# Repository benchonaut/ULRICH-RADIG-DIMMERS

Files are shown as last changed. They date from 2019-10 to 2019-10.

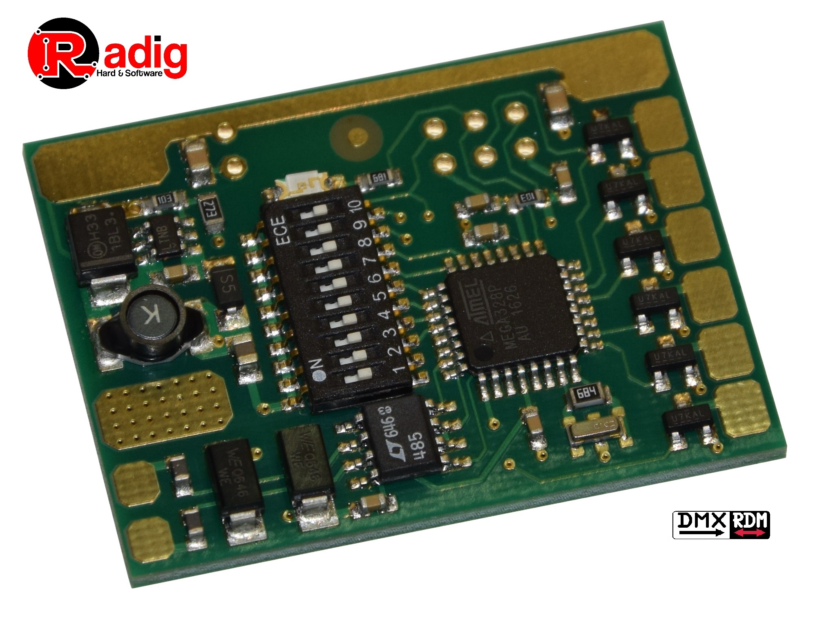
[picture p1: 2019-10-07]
DMX_6channel_LED_RDM/mini_DMX_RDM_Controller.JPG

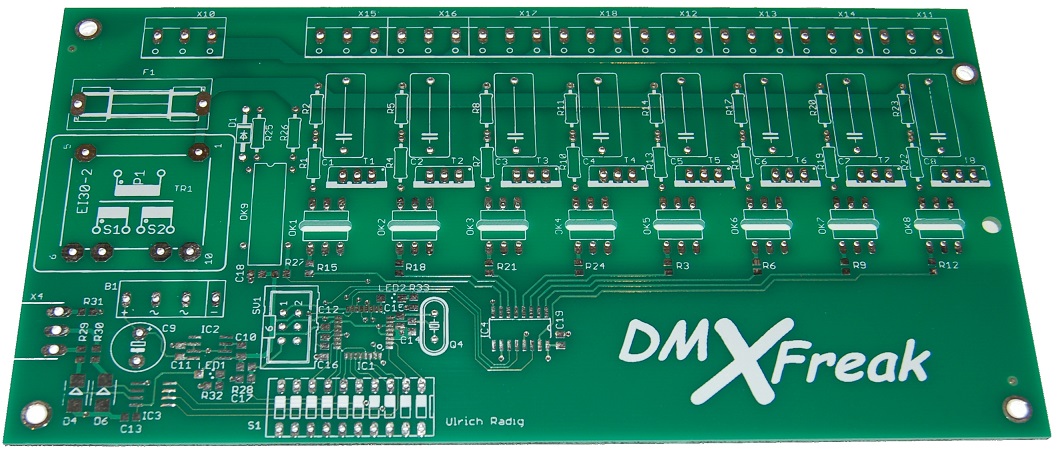
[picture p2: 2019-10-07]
DMX-8channel-V3/Bilder/DSC_0211.JPG

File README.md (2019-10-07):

## fixed code for dimmers from  ulrich-radig.de

#### intro:
in the 3 and 8 channel projects there are fixed 
dimmercurves from the forum named ...SKALIERT.c , 

( with the original calculation , dimming starts from ~35 % or dmx value 75 , this is also the point where voltage drops below 10v)

Since 
> (255-DMX_VAL)/2

will be max 128 or 127  and the dimmmer has 90 possible values from phase cutting ,
 the transformation is done as suggested in his forum[1] via valMap

hint: the values are reversed 100%=0 ,0%=90 internal 

#### install:
-> atmel studio 7 -> new project -> c++ -> stk5000 (find com .. ) -> atmega328p -> insert sourceode -> build solution (f7) -> "tools→add target" -> "tools→device programming" -> "read"(top) ->memories (check for build to appear) -> erase flash -> program 

[1]  https://www.ulrichradig.de/forum/viewtopic.php?f=53&t=2656s

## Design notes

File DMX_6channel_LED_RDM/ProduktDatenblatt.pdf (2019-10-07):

## 6 Kanal DMX RDM LED Controller

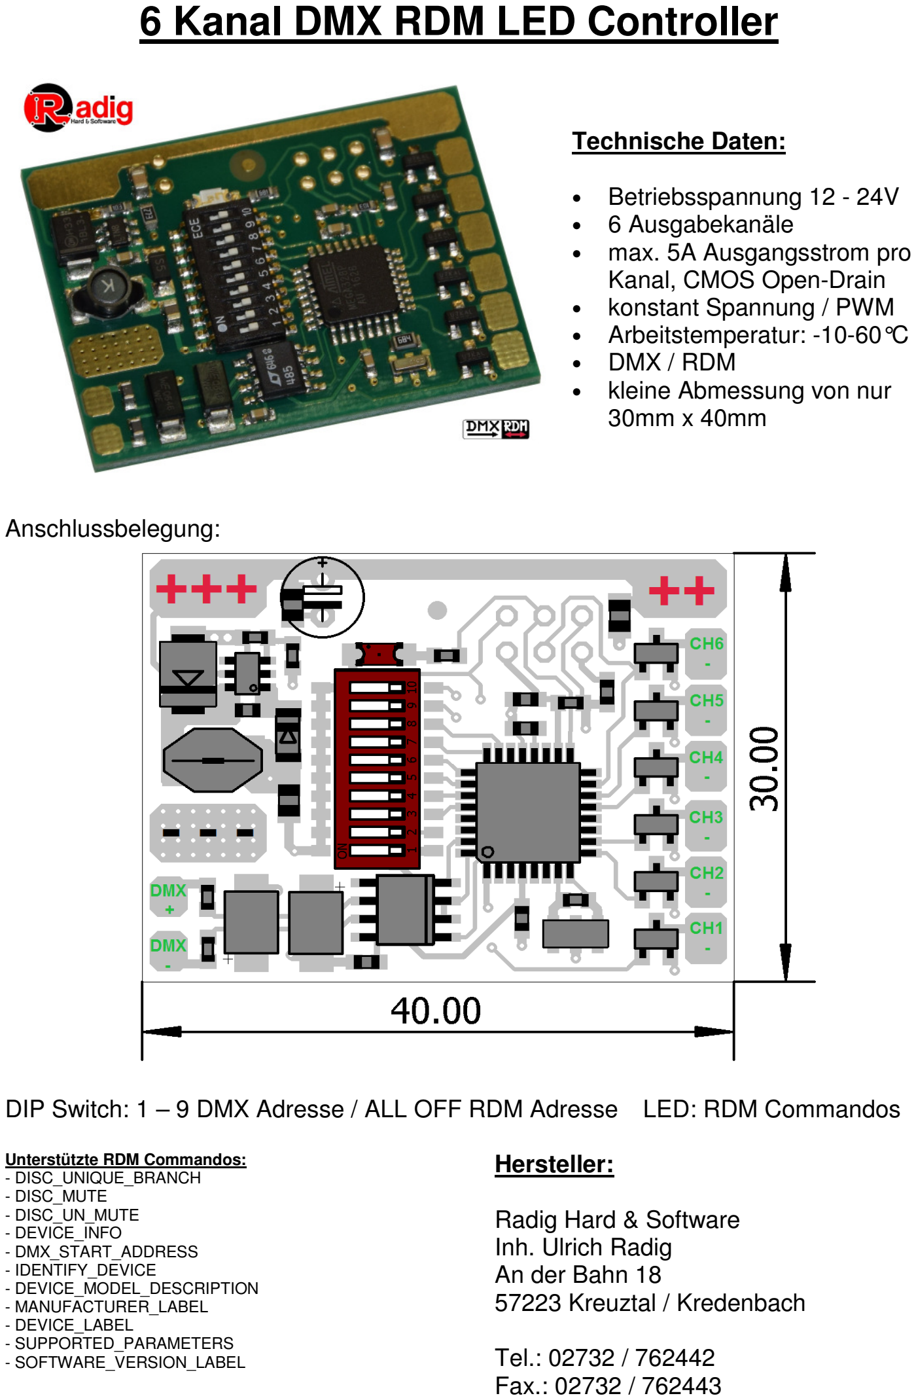
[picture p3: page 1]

Technische Daten:

- Betriebsspannung 12 - 24V
- 6 Ausgabekanäle
- max. 5A Ausgangsstrom pro Kanal, CMOS Open-Drain
- konstant Spannung / PWM
- Arbeitstemperatur: -10-60°C
- DMX / RDM
- kleine Abmessung von nur 30mm x 40mm

Anschlussbelegung:

DIP Switch: 1 – 9 DMX Adresse / ALL OFF RDM Adresse LED: RDM Commandos

Unterstützte RDM Commandos:
- DISC_UNIQUE_BRANCH
- DISC_MUTE
- DISC_UN_MUTE
- DEVICE_INFO
- DMX_START_ADDRESS
- IDENTIFY_DEVICE
- DEVICE_MODEL_DESCRIPTION
- MANUFACTURER_LABEL
- DEVICE_LABEL
- SUPPORTED_PARAMETERS
- SOFTWARE_VERSION_LABEL

Hersteller:

Radig Hard & Software
Inh. Ulrich Radig
An der Bahn 18
57223 Kreuztal / Kredenbach

Tel.: 02732 / 762442
Fax.: 02732 / 762443

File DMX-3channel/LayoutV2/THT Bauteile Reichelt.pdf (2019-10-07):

reichelt elektronik GmbH & Co. KG Elektronikring 1
26452 Sande

Tel.: +49 (0)4422 955-333
Fax.: +49 (0)4422 955-111
www.reichelt.de
Datum: 26.Aug.2012

Warenkorb

Artikel-Nr. | Bezeichnung | WG | Menge | Einzelpreis incl. MwSt.

Gesamtpreis
incl. MwSt.
B40C1500-WW+ | Brückengleichrichter | 1 | 1 | 0,26 € | 0,26 €
RAD 220/25 | Elektrolytkondensator, 8x11,5mm, RM 3,5mm | 1 | 1 | 0,040 € | 0,04 €
1N 4007 | Gleichrichterdiode, DO41, 1000V, 1A | 1 | 1 | 0,020 € | 0,02 €
PL 112000 | Sicherungshalter, 5x20mm, max. 6,3A-250V | 1 | 4 | 0,13 € | 0,50 €
TRÄGE 0,05A | Feinsicherung 5x20mm, träge 0,05A | 1 | 1 | 0,82 € | 0,82 €
TRÄGE 1,6A | Feinsicherung 5x20mm, träge 1,6A | 1 | 3 | 0,32 € | 0,96 €
S202 S01 | Solid-State-Relais, U: 600V, IT: 8,0A, Ift: 8mA | 1 | 3 | 3,65 € | 10,95 €
CAF 3,5-2,7 | Stromkompensierte Drossel, 2,7mH, 15/25mm | 1 | 1 | 1,95 € | 1,95 €
CNY 65 | OPTOKOPPLER | 1 | 1 | 1,00 € | 1,00 €
WSL 6G | Wannenstecker, 6-polig, gerade | 1 | 1 | 0,16 € | 0,16 €
1/4W 33K | Kohleschichtwiderstand 1/4W, 5%, 33 K-Ohm | 1 | 2 | 0,10 € | 0,21 €
DP 10 | Piano-Dip-Schalter, 10-polig | 1 | 1 | 0,64 € | 0,64 €
EI 30/12,5 209 | Trafo 1,5VA, 2x 9V, 2x 83mA | 1 | 1 | 2,50 € | 2,50 €
AKL 330-03 | Wannenstecker für AKL 349, 3-pol, RM5,0 | 1 | 4 | 0,40 € | 1,60 €
AKL 349-03 | Anschlussklemmensystem 3-pol, RM5,0 | 1 | 4 | 0,82 € | 3,28 €
PSS 254/3G | Printstecker, Einzelstecker, gerade, 3-polig | 1 | 1 | 0,050 € | 0,05 €
PSK 254/3W | Kupplungs-Leergehäuse, Crimptechnik, 3-polig | 1 | 1 | 0,050 € | 0,05 €
PSK-KONTAKTE | Crimpkontakte für psk 254/..., 20 Stück | 1 | 1 | 0,23 € | 0,23 €
Warenwert | | | | | 25,22 €
| | | | | ============
Zuzüglich Versandkosten innerhalb Deutschlands für ca. 0,2 kg bei Zahlung per Nachnahme | 8,06 €
Zuzüglich Versandkosten innerhalb Deutschlands für ca. 0,2 kg bei Zahlung per Bankeinzug/Re/Vorkasse | 5,60 €

Alle Preise in Euro inklusive gesetzl. Mehrwertsteuer.

Mit freundlichen Grüßen
Ihr reichelt elektronik Team
Notebook, PC Zubehör, Festplatte und Elektronik bei Reichelt | Seite 1 von 1
http://www.reichelt.de/index.html?IW=1;ACTION=505;SID=10UDpS3H8AAAIAA... | 26.08.2012

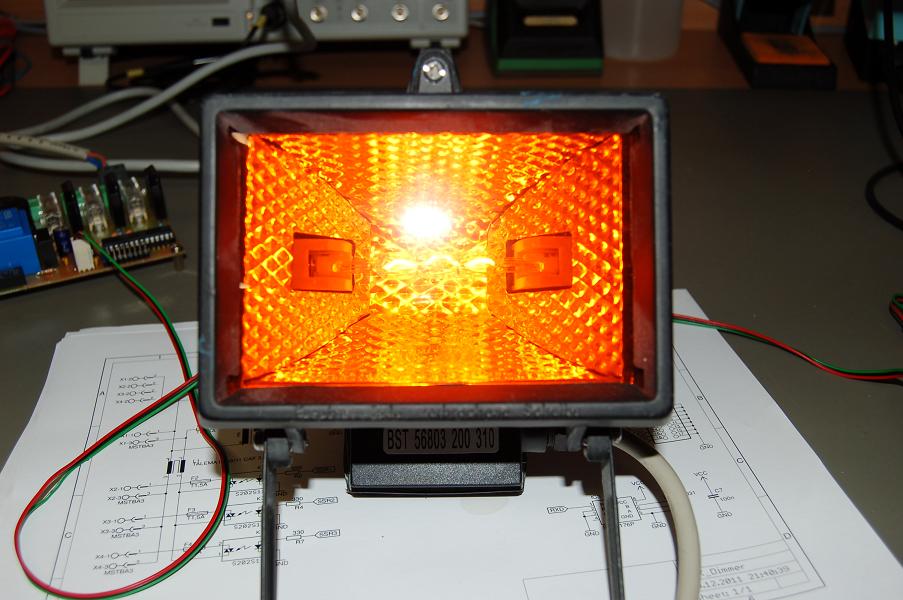
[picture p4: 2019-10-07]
DMX-3channel/Bilder/Strahler_Baumarkt.JPG

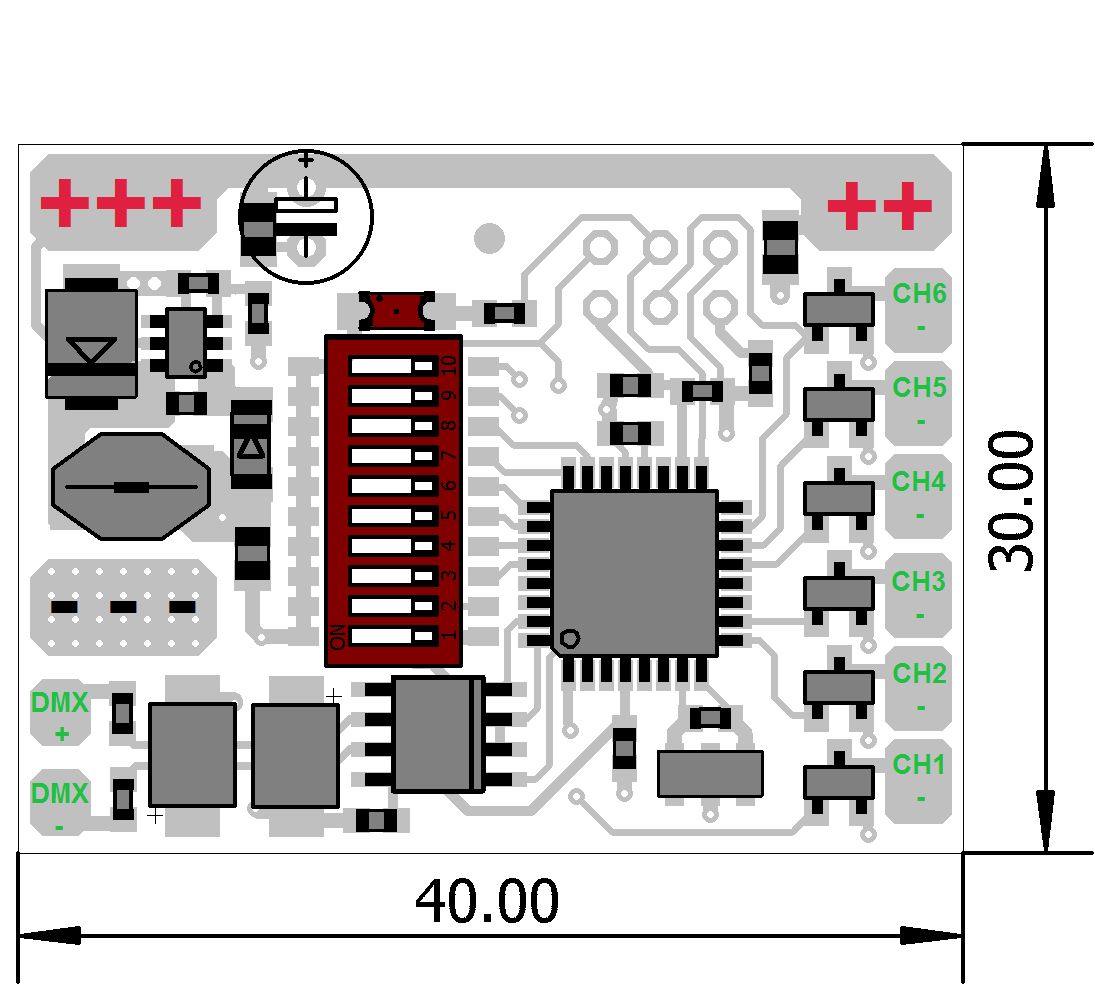
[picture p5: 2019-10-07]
DMX_6channel_LED_RDM/TOP.bmp

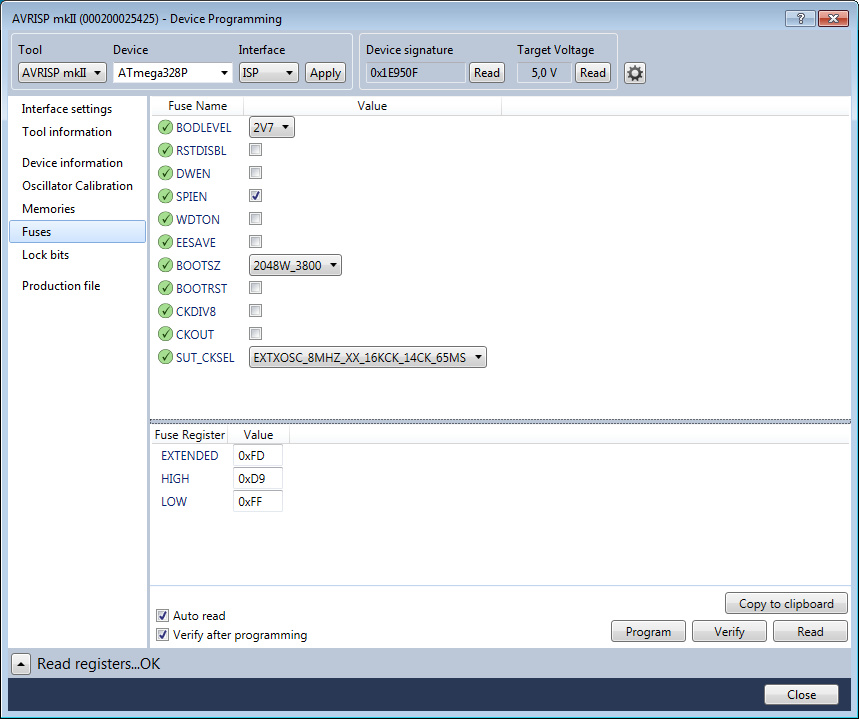
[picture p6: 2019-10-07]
DMX-8channel-V3/Hexfile/FuseBits.bmp

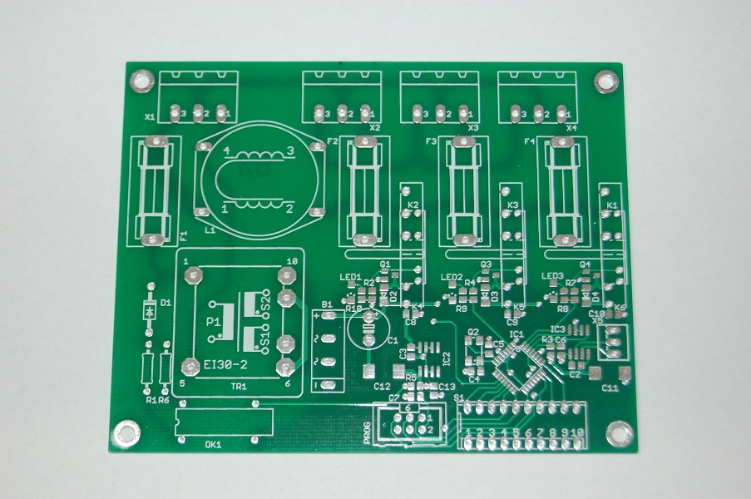
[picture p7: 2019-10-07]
DMX-3channel/Bilder/DMX Dimmer.JPG

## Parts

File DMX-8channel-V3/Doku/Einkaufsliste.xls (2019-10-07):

Part | Value | Menge | Stück Preis | Gesamt Preis | Lieferant | Bestellnr.
B1 | B40C2300/1500 +AC- | 1 | 0.33 € | 0.33 € | Reichelt | B40C1500-WW+ (https://www.reichelt.de/Gleichrichter/B40C1500-WW-/3/index.html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)
C1..C8 | 0.22µF 275V~ | 8 | 0.25 € | 2.00 € | Reichelt | PAN-X2-220N (https://www.reichelt.de/Funkentstoerkondensatoren/PAN-X2-220N/3/index.html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)
C9 | 220µF 35V | 1 | 0.05 € | 0.05 € | Reichelt | RAD 220/35 (https://www.reichelt.de/Elkos-radial-85-C/RAD-220-35/3/index.html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)
C10..C13,C16..C19 | 100n BF0805 | 8 | 0.04 € | 0.32 € | Reichelt | X7R-G0805 100N (https://www.reichelt.de/Vielschicht-SMD-G0805/X7R-G0805-100N/3/index.html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)
C14,C15 | 22p BF0805 | 2 | 0.04 € | 0.08 € | Reichelt | NPO-G0805 22P (https://www.reichelt.de/Vielschicht-SMD-G0805/NPO-G0805-22P/3/index.html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)
D1 | 1N4007 | 1 | 0.04 € | 0.04 € | Reichelt | 1N 4007 (https://www.reichelt.de/1N-UF-AA-Dioden/1N-4007/3/index.html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)
D4, D6 | SMBJ6,8 | 2 | 0.04 € | 0.08 € | Reichelt | SMD ZF 6,8 (https://www.reichelt.de/SMD-Z-Dioden-Mini-Melf/SMD-ZF-6-8/3/index.html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)
F1 | Halter | 1 | 0.29 € | 0.29 € | Reichelt | RND 170-00001 (https://www.reichelt.de/Sicherungshalter/RND-170-00001/3/index.html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)
F1 | Kappe | 1 | 0.11 € | 0.11 € | Reichelt | RND 170-00007 (https://www.reichelt.de/Sicherungshalter/RND-170-00007/3/index.html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)
F1 | T3,15 | 1 | 0.33 € | 0.33 € | Reichelt | TR 3,15A (https://www.reichelt.de/5x20mm-Feinsicherungen/TR-3-15A/3/index.html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)
IC1 | MEGA328P-AU | 1 | 2.50 € | 2.50 € | Reichelt | ATMEGA 328P-AU (https://www.reichelt.de/Atmel-ATMega-AVRs/ATMEGA-328P-AU/3/index.html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)
IC2 | 78L05S SO8 | 1 | 0.14 € | 0.14 € | Reichelt | µA 78L05 SMD (https://www.reichelt.de/ICs-A-A-/-A-78L05-SMD/3/index.html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)
IC3 | SN75176 SO8 | 1 | 0.26 € | 0.26 € | Reichelt | SN 75176BD (https://www.reichelt.de/ICs-74F-74ALS-SN75-/SN-75176BD/3/index.html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)
IC4 | 74HC595 | 1 | 0.20 € | 0.20 € | Reichelt | SMD HC 595 (https://www.reichelt.de/ICs-74HC-SMD/SMD-HC-595/3/index.html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)
LED1, LED2 | LED1206 BLAU | 2 | 0.12 € | 0.24 € | Reichelt | LED EL 1206 BL (https://www.reichelt.de/SMD-LEDs-Standard/LED-EL-1206-BL/3/index.html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)
OK1..OK8 | MOC3022 | 8 | 0.31 € | 2.48 € | Reichelt | MOC 3022 (https://www.reichelt.de/Optokoppler/MOC-3022/3/index.html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)
OK9 | CNY65 | 1 | 1.15 € | 1.15 € | Reichelt | CNY 65 (https://www.reichelt.de/Optokoppler/CNY-65/3/index.html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)
Q4 | 12MHz HC49S | 1 | 0.22 € | 0.22 € | Reichelt | 12,0000-HC49U-S (https://www.reichelt.de/Quarze/12-0000-HC49U-S/3/index.html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)
R1,R4,R7,R10,R13,R16, R19,R22 | 270 Ohm BF0207 | 8 | 0.09 € | 0.72 € | Reichelt | METALL 270 (https://www.reichelt.de/0-6W-1-100-Ohm-976-Ohm/METALL-270/3/index.html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)
R2,R5,R8,R11,R14,R17, R20,R23 | 1K 1W BF0207 | 8 | 0.16 € | 1.28 € | Reichelt | 1W 1,0K (https://www.reichelt.de/1W-5-1-0-k-Ohm-820-k-Ohm/1W-1-0K/3/index.html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)
R3,R6,R9,R12,R15,R18, R21,R24 | 390Ohm BF0805 | 8 | 0.02 € | 0.16 € | Reichelt | RND 0805 1 390 (https://www.reichelt.de/SMD-0805-von-0-bis-910-Ohm/RND-0805-1-390/3/index.html?ACTION=3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)
R25, R26 | 33k BF0207 | 2 | 0.09 € | 0.18 € | Reichelt | METALL 33,0K (https://www.reichelt.de/0-6W-1-10-0-k-Ohm-95-3-k-Ohm/METALL-33-0K/3/index.html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)
R27,R28 | 10k BF0805 | 2 | 0.02 € | 0.04 € | Reichelt | RND 0805 1 10K (https://www.reichelt.de/SMD-0805-von-1-bis-910-kOhm/RND-0805-1-10K/3/index.html?ACTION=3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)
R29, R30 | 10Ohm BF0805 | 2 | 0.02 € | 0.04 € | Reichelt | RND 0805 1 10 (https://www.reichelt.de/SMD-0805-von-0-bis-910-Ohm/RND-0805-1-10/3/index.html?ACTION=3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)
R31 | 100Ohm BF0805 | 1 | 0.02 € | 0.02 € | Reichelt | RND 0805 1 100 (https://www.reichelt.de/SMD-0805-von-0-bis-910-Ohm/RND-0805-1-100/3/index.html?ACTION=3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)
R32, R33 | 1k BF0805 | 2 | 0.02 € | 0.04 € | Reichelt | RND 0805 1 1,0K (https://www.reichelt.de/SMD-0805-von-1-bis-910-kOhm/RND-0805-1-1-0K/3/index.html?ACTION=3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)
S1 | DIP_SW10 | 1 | 0.33 € | 0.33 € | Reichelt | NT 10 (https://www.reichelt.de/Dip-Kodierschalter/NT-10/3/index.html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)
SV1 | WSL 6 | 1 | 0.16 € | 0.16 € | Reichelt | WSL 6G (https://www.reichelt.de/Pfosten-Wannenstecker/WSL-6G/3/index.html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)
T1..T8 | TIC206 TO220 | 8 | 0.56 € | 4.48 € | Reichelt | TIC 206D (https://www.reichelt.de/Triacs/TIC-206D/3/index.html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)
TR1 | TRAFO EI30-2 9V 2x0,6VA | 1 | 2.80 € | 2.80 € | Reichelt | EI 30/10,5 209 (https://www.reichelt.de/Printtrafos-1-0-1-8VA/EI-30-10-5-209/3/index.html?ACTION=3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)
X4 | 3POL STECKER | 1 | 0.40 € | 0.40 € | Reichelt | AKL 182-03 (https://www.reichelt.de/Wannenstecker/AKL-182-03/3/index.html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)
X4 | 3POL STECKER | 1 | 0.77 € | 0.77 € | Reichelt | AKL 169-03 (https://www.reichelt.de/Steckbare-Anschlussklemmen/AKL-169-03/3/index.html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)
X10..X18 | ANREIKLEMMEN | 9 | 0.24 € | 2.16 € | Reichelt | RND 205-00035 (https://www.reichelt.de/RND-connect/RND-205-00035/3/index.html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)
 |  |  | Gesamtpreis | 24.40 €

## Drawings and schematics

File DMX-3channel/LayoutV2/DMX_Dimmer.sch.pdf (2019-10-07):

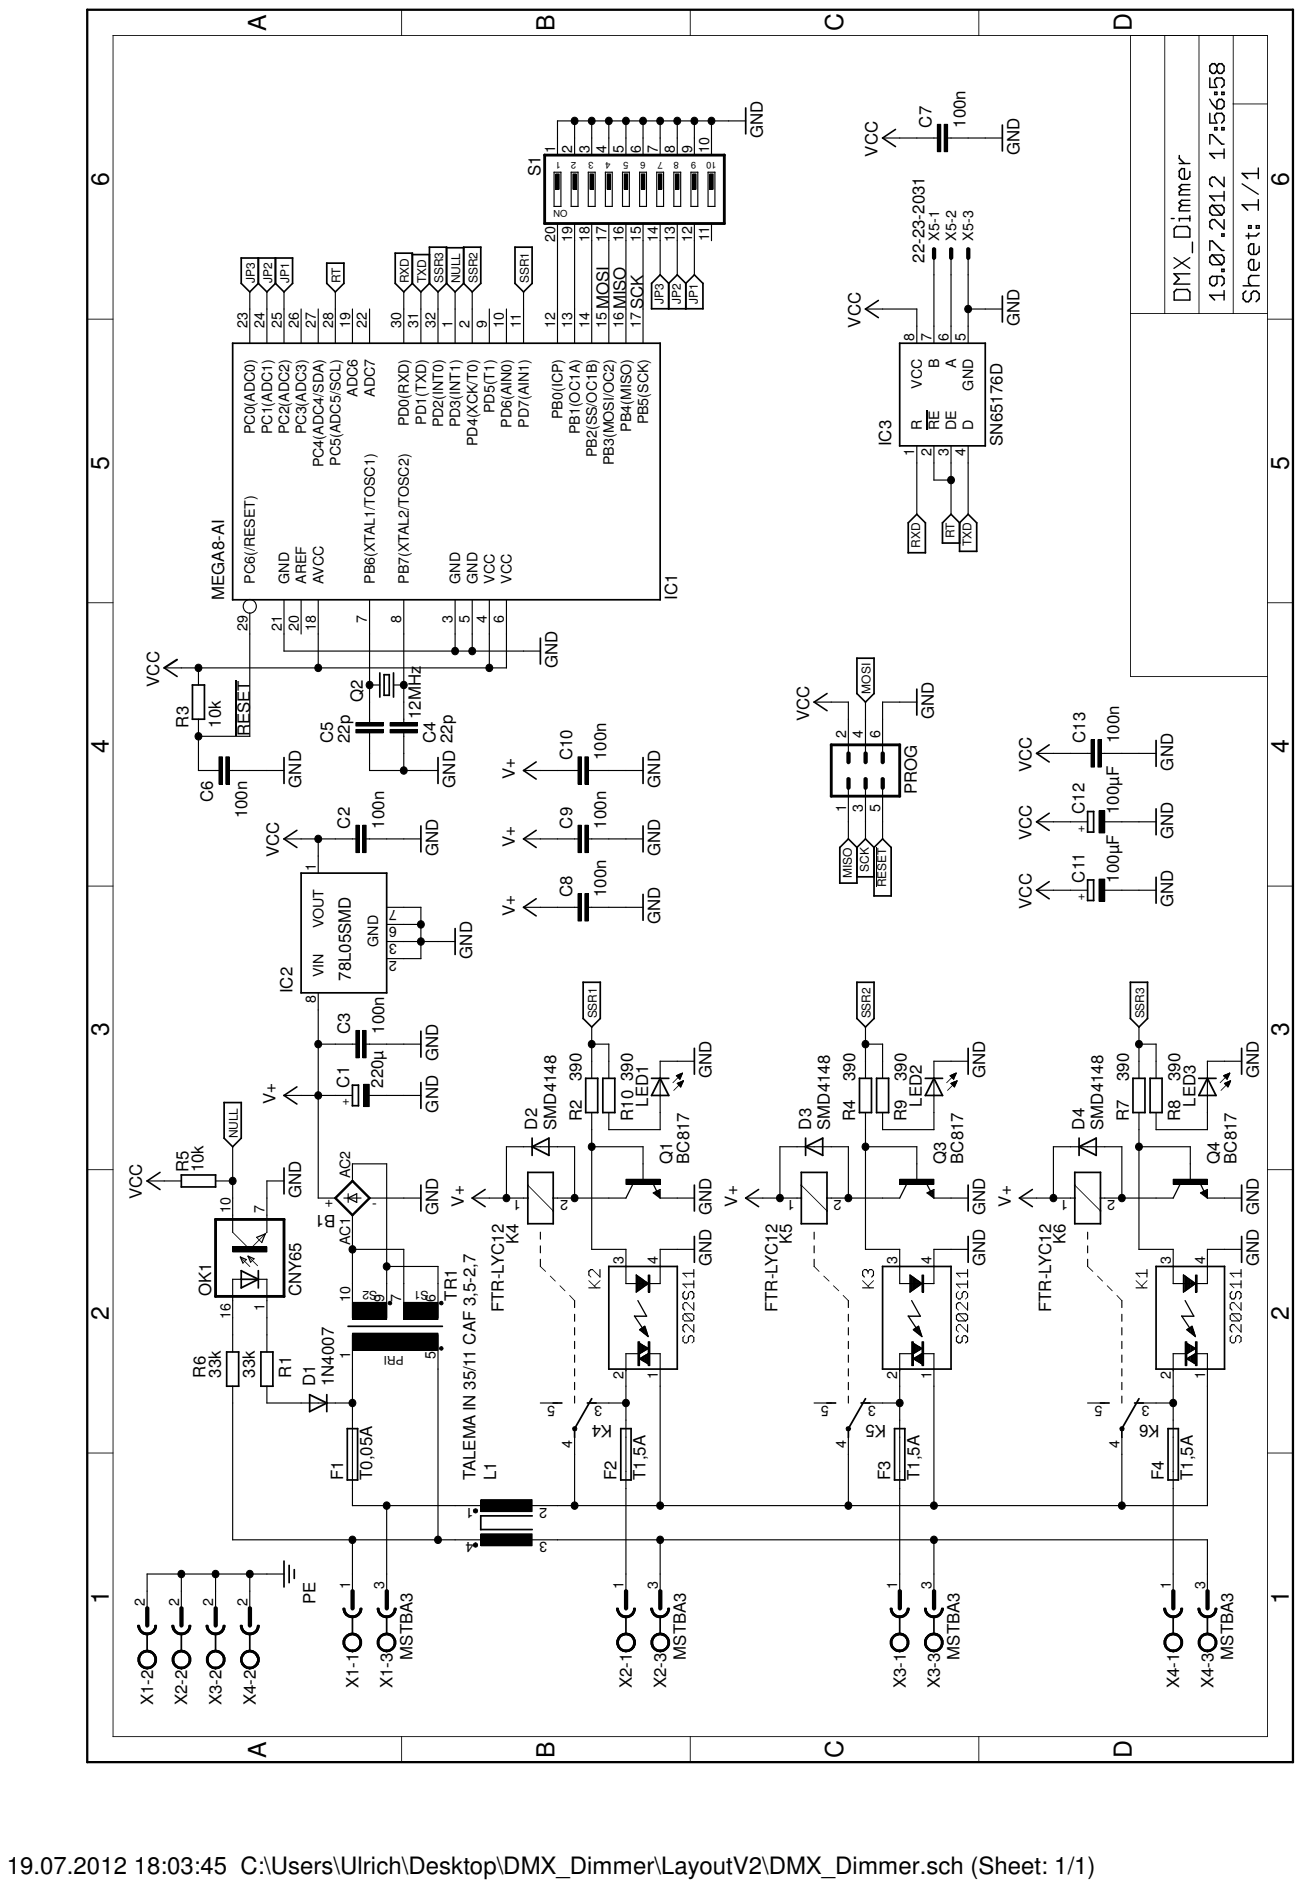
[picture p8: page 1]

PB4(MISO) 16 PB3(MOSI/OC2) 15 PB2(SS/OC1B) 14 PB1(OC1A) 13 PB0(ICP) 12

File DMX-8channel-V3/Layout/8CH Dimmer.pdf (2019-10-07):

A

A

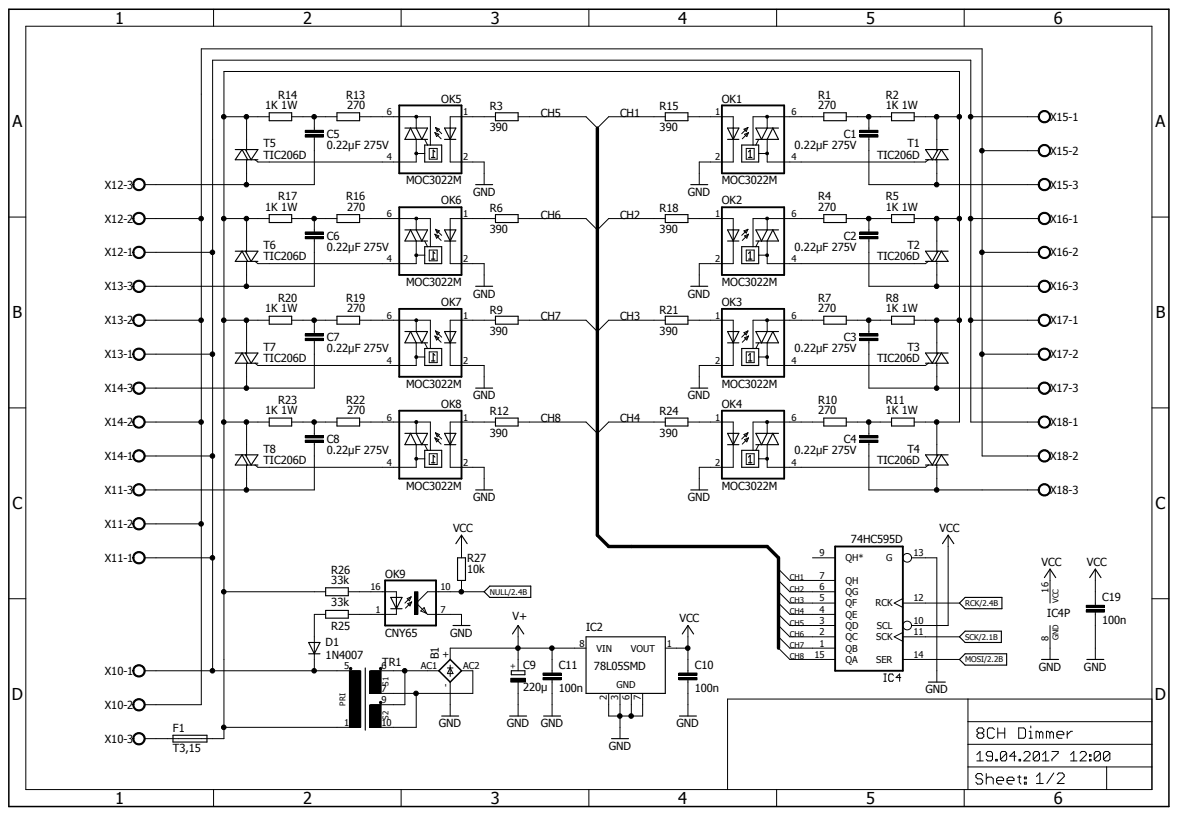
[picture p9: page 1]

A

A

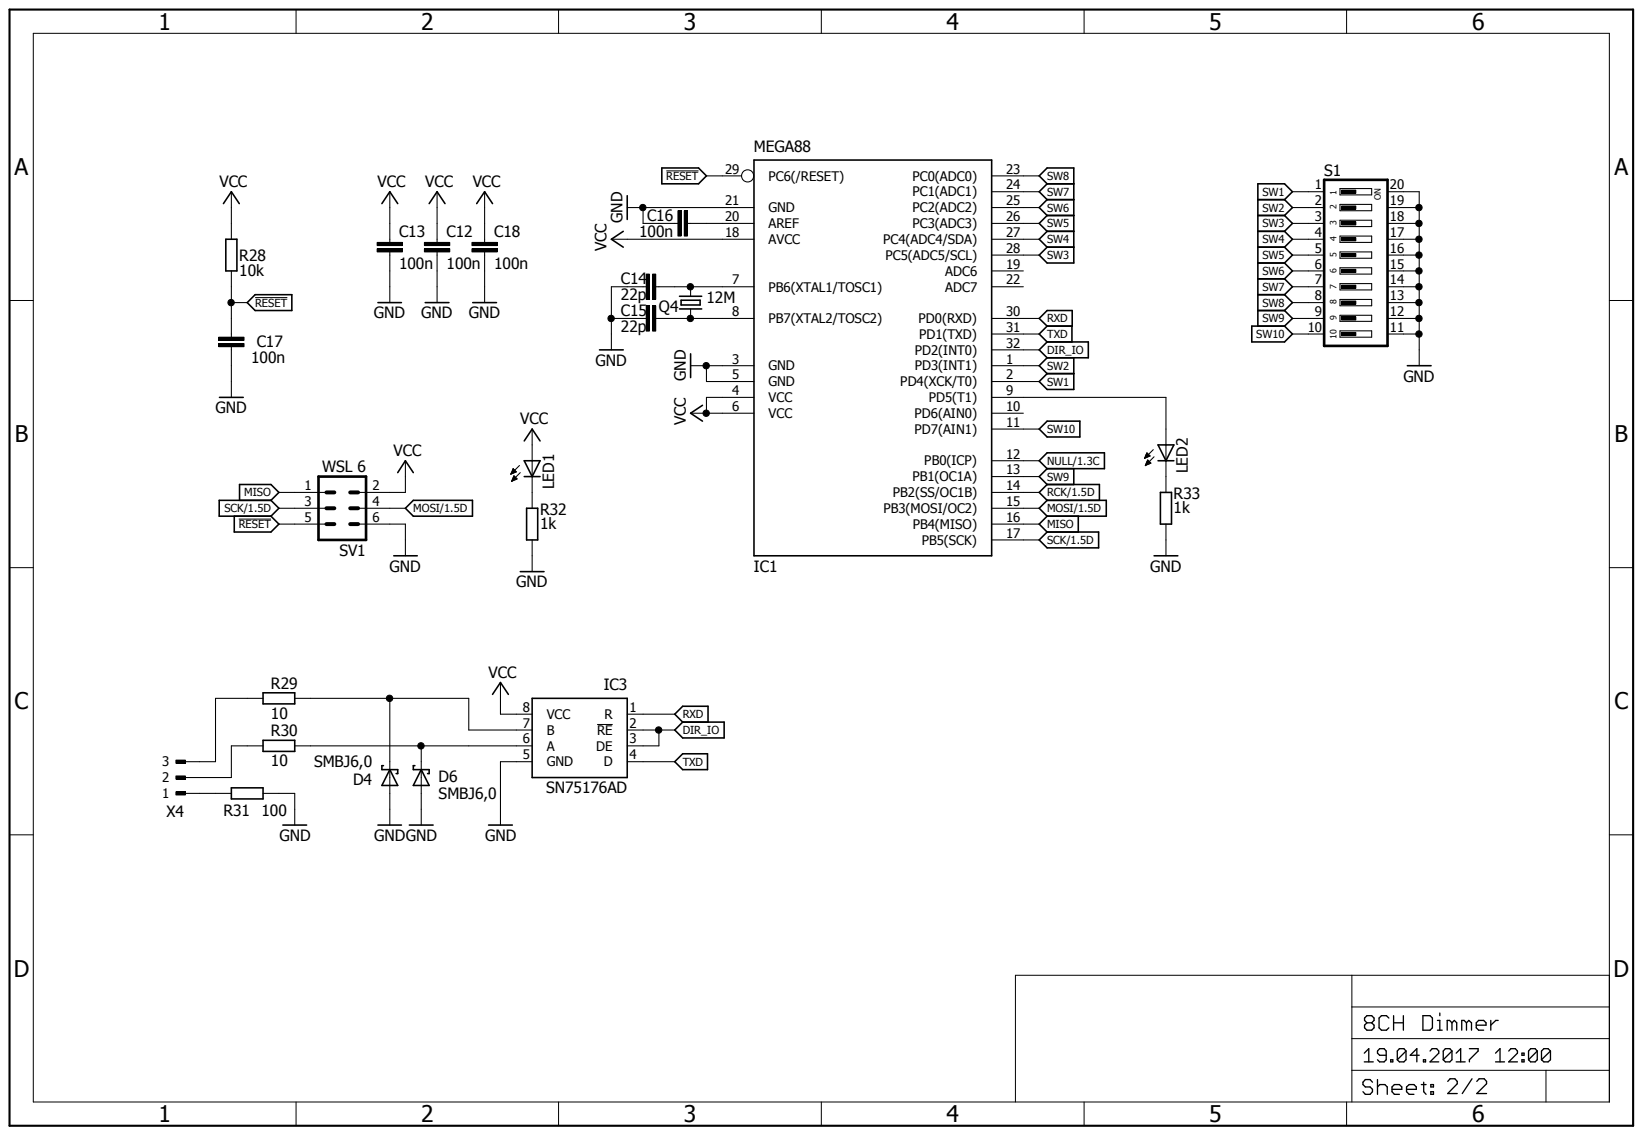
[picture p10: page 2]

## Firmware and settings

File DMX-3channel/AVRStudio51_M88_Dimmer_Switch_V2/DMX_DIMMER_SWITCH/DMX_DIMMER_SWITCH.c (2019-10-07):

/*------------------------------------------------------------------------------
 Copyright:      Radig Ulrich  mailto: mail@ulrichradig.de
 Author:         Radig Ulrich
 Remarks:        
 known Problems: none
 Version:        18.12.2011
 Description:    DMX_3Kanal_Dimmer


 Dieses Programm ist freie Software. Sie können es unter den Bedingungen der 
 GNU General Public License, wie von der Free Software Foundation veröffentlicht, 
 weitergeben und/oder modifizieren, entweder gemäß Version 2 der Lizenz oder 
 (nach Ihrer Option) jeder späteren Version. 

 Die Veröffentlichung dieses Programms erfolgt in der Hoffnung, 
 daß es Ihnen von Nutzen sein wird, aber OHNE IRGENDEINE GARANTIE, 
 sogar ohne die implizite Garantie der MARKTREIFE oder der VERWENDBARKEIT 
 FÜR EINEN BESTIMMTEN ZWECK. Details finden Sie in der GNU General Public License. 

 Sie sollten eine Kopie der GNU General Public License zusammen mit diesem 
 Programm erhalten haben. 
 Falls nicht, schreiben Sie an die Free Software Foundation, 
 Inc., 59 Temple Place, Suite 330, Boston, MA 02111-1307, USA. 
------------------------------------------------------------------------------*/

#include <avr/interrupt.h>
#include <avr/io.h>
#include <stdio.h>

#define F_CPU 12000000

//Relais or SSR SSR = 1 Relais = 0
#define SSR_RELAIS1		1
#define SSR_RELAIS2		1
#define SSR_RELAIS3		1

#define SSR1_PIN_OUT DDRD |= (1<<PD7);
#define SSR2_PIN_OUT DDRD |= (1<<PD4);
#define SSR3_PIN_OUT DDRD |= (1<<PD2);

#define SSR1_ON		PORTD |= (1<<PD7);
#define SSR1_OFF	PORTD &= ~(1<<PD7);
#define SSR2_ON		PORTD |= (1<<PD4);
#define SSR2_OFF	PORTD &= ~(1<<PD4);
#define SSR3_ON		PORTD |= (1<<PD2);
#define SSR3_OFF	PORTD &= ~(1<<PD2);


#define DMX_BAUD 250000
#define DMX_LOST_TIMEOUT 8000

// map table with 255 values. Three times the same value scaled down at the end
//uint8_t valMap[] = {90,89,89,88,88,87,87,...7,7,6,6,5,5,4,4,3,3,2,2,1,0,0};
	
volatile unsigned char dmx_buffer[514];
volatile unsigned int dmx_lost = DMX_LOST_TIMEOUT;

volatile unsigned int dmx_adresse = 0;
volatile unsigned char phase_off_count = 0;

volatile unsigned char val1;
volatile unsigned char val2;
volatile unsigned char val3;

//############################################################################
//Empfangsroutine für DMX
ISR (USART_RX_vect)
//############################################################################
{
	static unsigned int dmx_channel_rx_count = 0;
	static unsigned char dmx_valid = 0;
	unsigned char tmp = 0;
	
	tmp =  UDR0;
	
	if(UCSR0A&(1<<FE0))
	{
		if(dmx_channel_rx_count > 1)
		{
			dmx_lost = 0;
		}
		dmx_channel_rx_count = 0;	
		dmx_buffer[0] = tmp;
		if(dmx_buffer[0] == 0)
		{
			dmx_valid = 1;
			dmx_channel_rx_count++;
		}
		else
		{
			dmx_valid = 0;
		}
		return;
	}
	
	if(dmx_valid)
	{
		dmx_buffer[dmx_channel_rx_count] = tmp;	
		if(dmx_channel_rx_count < 514)
		{
			dmx_channel_rx_count++;
		}
		return;
	}
}

//############################################################################
//Hier wird die Zeit gezählt (Tick 100µs)
ISR (TIMER2_COMPA_vect)
//############################################################################
{
	phase_off_count++;
	
	if(phase_off_count > 90) phase_off_count = 0;
	
	#if SSR_RELAIS1
		if(phase_off_count>val1)
		{
			SSR1_ON
		}
		else
		{
			SSR1_OFF
		}
	#endif
	
	#if SSR_RELAIS2
		if(phase_off_count>val2)
		{
			SSR2_ON
		}
		else
		{
			SSR2_OFF
		}
	#endif
	
	#if SSR_RELAIS3
		if(phase_off_count>val3)
		{
			SSR3_ON
		}
		else
		{
			SSR3_OFF
		}
	#endif

	if(dmx_lost<DMX_LOST_TIMEOUT)
	{
		dmx_lost++;
	}
}

//############################################################################
//ISR vom externen Interrupt (Zero cross detection)
ISR (INT1_vect)
//############################################################################
{
	TCNT2 = 0;
	phase_off_count = 0;
}

//############################################################################
//Hauptprogramm
int main (void) 
//############################################################################
{  
	unsigned int dmx_adresse_tmp;
	
	//INT1 ON PHASE SYNC
	EICRA |= (1<<ISC11)|(1<<ISC10); //The rising edge of INT1 generates an interrupt request
	EIMSK |= (1<<INT1); //External interrupt request 1 enable

	//Init usart DMX-BUS
	UBRR0   = (F_CPU / (DMX_BAUD * 16L) - 1);
	UCSR0B|=(1 << RXEN0 | 1<< RXCIE0);
	UCSR0C|=(1<<USBS0); //USBS0 2 Stop bits	
	sei();//Globale Interrupts Enable
	
	//Timer für die Phasenanschnittberechnung ( alle 100usec )
	TCCR2A |= (1<<WGM21);
	TCCR2B |= (1<<CS22|1<<CS21);
	TIMSK2 |= (1<<OCIE2A);
	OCR2A = F_CPU/256/2/50/92 - 1;
		
	SSR1_PIN_OUT;
	SSR2_PIN_OUT;
	SSR3_PIN_OUT;
	SSR1_OFF;
	SSR2_OFF;
	SSR3_OFF;
	
	DDRC = (1<<PC5);
	PORTB |= 0x3F;
	PORTC |= 0xFF;
	PORTC &=~(1<<PC5);
	
	//Endlosschleife
	while(1)
	{
		dmx_adresse_tmp = 0;
		
		if(!(PINB&(1<<PB0))) dmx_adresse_tmp |= 0x01;
 		if(!(PINB&(1<<PB1))) dmx_adresse_tmp |= 0x02;
		if(!(PINB&(1<<PB2))) dmx_adresse_tmp |= 0x04;
		if(!(PINB&(1<<PB3))) dmx_adresse_tmp |= 0x08;
		if(!(PINB&(1<<PB4))) dmx_adresse_tmp |= 0x10;
		if(!(PINB&(1<<PB5))) dmx_adresse_tmp |= 0x20;
		
		if(!(PINC&(1<<PC0))) dmx_adresse_tmp |= 0x40;
		if(!(PINC&(1<<PC1))) dmx_adresse_tmp |= 0x80;
		if(!(PINC&(1<<PC2))) dmx_adresse_tmp |= 0x0100;
		
		if(dmx_adresse != dmx_adresse_tmp) dmx_adresse =  dmx_adresse_tmp;	
		
		
		//new calculation of val1
		//val1 = valMap[dmx_buffer[dmx_adresse]];
		val1 = (255 - dmx_buffer[dmx_adresse])/2;
		val2 = (255 - dmx_buffer[dmx_adresse+1])/2;
		val3 = (255 - dmx_buffer[dmx_adresse+2])/2;
		
		#if (!SSR_RELAIS1)
			if(val1 > 64)
			{
				SSR1_ON;
			}
			else
			{
				SSR1_OFF;
			}	
		#endif
		
		#if (!SSR_RELAIS2)
			if(val2 > 64)
			{
				SSR2_ON;
			}
			else
			{
				SSR2_OFF;
			}	
		#endif 
		
		#if (!SSR_RELAIS3)
			if(val3 > 64)
			{
				SSR3_ON;
			}
			else
			{
				SSR3_OFF;
			}	
		#endif 
		
		if(dmx_lost==DMX_LOST_TIMEOUT)
		{
			dmx_buffer[dmx_adresse] = 0;
			dmx_buffer[dmx_adresse+1] = 0;
			dmx_buffer[dmx_adresse+2] = 0;
		}
	}
}

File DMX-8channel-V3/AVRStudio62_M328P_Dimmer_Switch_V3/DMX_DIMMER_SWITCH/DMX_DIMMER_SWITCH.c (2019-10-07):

/*------------------------------------------------------------------------------
 Copyright:      Radig Ulrich  mailto: mail@ulrichradig.de
 Author:         Radig Ulrich
 Remarks:        
 known Problems: none
 Version:        19.04.2017
 Description:    DMX_8 Kanal_Dimmer
------------------------------------------------------------------------------*/

#include <avr/interrupt.h>
#include <avr/io.h>
#include <stdio.h>

#define F_CPU 12000000

#define LED_OUT		DDRD |= (1<<PD5);
#define LED_TOGGLE	PORTD ^= (1<<PD5);

#define DMX_BAUD 250000
#define DMX_LOST_TIMEOUT 8000

// map table with 255 values. Three times the same value scaled down at the end
//uint8_t valMap[] = {90,89,89,88,88,87,87,...7,7,6,6,5,5,4,4,3,3,2,2,1,0,0};
	
volatile unsigned char dmx_buffer[513];
volatile unsigned int dmx_lost = DMX_LOST_TIMEOUT;

volatile unsigned int dmx_adresse = 0;
volatile unsigned char phase_on_count = 0;

volatile unsigned char val[8];

#define SPI_DDR                 DDRB
#define SPI_PORT                PORTB
#define SPI_SCK                 5
#define SPI_MOSI                3
#define CS_595                  2

#define CS_595_HI()				PORTB &= ~(1<<CS_595)
#define CS_595_LO()				PORTB |= (1<<CS_595)

//############################################################################
//Empfangsroutine für DMX
ISR (USART_RX_vect){
	static unsigned int dmx_channel_rx_count = 0;
	static unsigned char dmx_valid = 0;
	unsigned char tmp = 0;
	
	tmp =  UDR0;
	
	if(UCSR0A&(1<<FE0)){
		if(dmx_channel_rx_count > 1){
			dmx_lost = 0;
		}
		dmx_channel_rx_count = 0;	
		dmx_buffer[0] = tmp;
		if(dmx_buffer[0] == 0){
			dmx_valid = 1;
			dmx_channel_rx_count++;
		}else{
			dmx_valid = 0;
		}
		return;
	}
	
	if(dmx_valid){
		dmx_buffer[dmx_channel_rx_count] = tmp;	
		if(dmx_channel_rx_count < 513)
		{
			dmx_channel_rx_count++;
		}
		return;
	}
}

//############################################################################
//Porterweiterung OUTPUT 1 - 8 via SPI-BUS
void out_ext (unsigned char value){
	CS_595_LO();
	SPDR = value;
	while( !(SPSR & (1<<SPIF)) ) ;
	CS_595_HI();
}

//############################################################################
//
static inline void spi_init(void){
	// configure pins MOSI, SCK and CS595 as output
	SPI_DDR |= (1<<SPI_MOSI) | (1<<SPI_SCK) | (1<<CS_595);
	// pull SCK high
	SPI_PORT |= (1<<SPI_SCK);
	//SPI: enable, master, positive clock phase, msb first, SPI speed fosc/2
	SPCR = (1<<SPE) | (1<<MSTR);
	SPSR = (1<<SPI2X);
	
	out_ext(0x00);
}

//############################################################################
//Hier wird die Zeit gezählt (Tick 100µs)
ISR (TIMER2_COMPA_vect)
{
	unsigned char out = 0;
	unsigned char tmp = 0;
	phase_on_count++;
	
	if(phase_on_count > 240){
		phase_on_count = 0;
	}
	
	for(tmp = 0;tmp <8;tmp++){
		if(phase_on_count>val[tmp]) out |= (1<<tmp);
	}
	out_ext(out);
	
	if(dmx_lost<DMX_LOST_TIMEOUT){
		dmx_lost++;
	}
}

//############################################################################
//ISR vom externen Interrupt (ICP)
ISR (PCINT0_vect){
	TCNT2 = 0;
	phase_on_count = 0;
}

//############################################################################
//Hauptprogramm
int main (void) 
{  
	unsigned int dmx_adresse_tmp = 0;
	unsigned char tmp = 0;
	unsigned int live_counter = 0;

	LED_OUT;
	spi_init();
		
	//PIN CHANGE INTERRUPT ON PHASE SYNC
	PCICR |= (1<<PCIE0);
	PCMSK0 |= (1<<PCINT0);

	//Init usart DMX-BUS
	UBRR0   = (F_CPU / (DMX_BAUD * 16L) - 1);
	UCSR0B|=(1 << RXEN0 | 1<< RXCIE0);
	UCSR0C|=(1<<USBS0); //USBS0 2 Stop bits	
	sei();//Globale Interrupts Enable
	
	//Switch 75176 to INPUT RXD
	DDRD |= (1<<PD2);
	PORTD &= ~(1<<PD2);
	
	//Timer für die Phasenanschnittberechnung
	TCCR2A |= (1<<WGM21);
	TCCR2B |= (1<<CS21|1<<CS20); // :32
	TIMSK2 |= (1<<OCIE2A);

	// :32 Teiler
	// :2 Clock Source 
	// :50 Hz
	// :92 - 1 Stepping
	
	OCR2A = (F_CPU/32/2/50/240) - 1;
	
	//Pullup for DIP Switch
	PORTD |= (1<<PD3)|(1<<PD4)|(1<<PD7);
	PORTC |= (1<<PC5)|(1<<PC4)|(1<<PC3)|(1<<PC2)|(1<<PC1)|(1<<PC0);
	PORTB |= (1<<PB1);
	
	//Endlosschleife
	while(1){
		//Read DMX Address from Switch
		dmx_adresse_tmp = 0;
		if(!(PIND&(1<<PD4))) dmx_adresse_tmp |= 0x01;
 		if(!(PIND&(1<<PD3))) dmx_adresse_tmp |= 0x02;
		if(!(PINC&(1<<PC5))) dmx_adresse_tmp |= 0x04;
		if(!(PINC&(1<<PC4))) dmx_adresse_tmp |= 0x08;
		if(!(PINC&(1<<PC3))) dmx_adresse_tmp |= 0x10;
		if(!(PINC&(1<<PC2))) dmx_adresse_tmp |= 0x20;
		if(!(PINC&(1<<PC1))) dmx_adresse_tmp |= 0x40;
		if(!(PINC&(1<<PC0))) dmx_adresse_tmp |= 0x80;
		if(!(PINB&(1<<PB1))) dmx_adresse_tmp |= 0x0100;
		
		if(dmx_adresse_tmp == 0) dmx_adresse_tmp = 1;  
		if(dmx_adresse_tmp > 505) dmx_adresse_tmp = 505;
		if(dmx_adresse != dmx_adresse_tmp) dmx_adresse =  dmx_adresse_tmp;	
		
		//new calculation of val
		if(PIND&(1<<PD7)){
			for(tmp = 0;tmp <8;tmp++){
				val[tmp] = (255 - dmx_buffer[dmx_adresse+tmp]);
			}
		}else{
			for(tmp = 0;tmp <8;tmp++){
				if(dmx_buffer[dmx_adresse+tmp]>128){
					val[tmp] = 0;
				}
				else{
					val[tmp] = 255;
				}
			}
		}
		
		if(dmx_lost==DMX_LOST_TIMEOUT){
			for(tmp = 0;tmp <8;tmp++){
				dmx_buffer[dmx_adresse + tmp] = 0;
			}
		}
		
		if((live_counter++) > 10000) {
			LED_TOGGLE;
			live_counter = 0;
		}
		
	}
}
